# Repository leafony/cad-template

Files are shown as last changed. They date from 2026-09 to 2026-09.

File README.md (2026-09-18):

# Leafony CAD Templates

[Leafony](https://leafony.com/)の拡張リーフ基板を設計するためのCADテンプレート集です。基板外形、Leafony busの接続部、デザインルールなどを設定した設計データを、KiCadとCR-8000 Design Force向けに収録しています。

## 収録テンプレート

| CAD | 使用するバージョン | 内容・使い方 |
| --- | --- | --- |
| KiCad | 10.0系 | 回路図、PCB、プロジェクト設定、専用ライブラリ。[設定・利用手順](KiCad/README.md) |
| CR-8000 Design Force | 2020以降（同梱readmeの記載） | 設計データとライブラリ一覧を含む[ZIPアーカイブ](DesignForce/Leafony_Template/Design_Force_Leafony_Template.zip) |

KiCad版の回路図・PCBはKiCad 10.0形式で保存されています。以前のREADMEにあった「KiCad 6.0.0以降」は、現在のファイルには適用されません。

```text
cad-template/
├── KiCad/
│   ├── README.md
│   ├── Leafony_Template/
│   │   ├── Leafony_Template.kicad_pro   # プロジェクト設定
│   │   ├── Leafony_Template.kicad_sch   # 回路図
│   │   ├── Leafony_Template.kicad_pcb   # 基板レイアウト
│   │   ├── sym-lib-table / fp-lib-table
│   │   ├── lib/                        # 専用シンボル・フットプリント
│   │   └── meta/                       # テンプレート選択画面用の情報
│   └── img/
└── DesignForce/
    └── Leafony_Template/
        └── Design_Force_Leafony_Template.zip
```

## ダウンロード

リポジトリをクローンしてください。

```sh
git clone https://github.com/leafony/cad-template.git
```

Gitを使わない場合は、[GitHubのリポジトリページ](https://github.com/leafony/cad-template)で **Code → Download ZIP** を選び、ダウンロードしたZIPを展開します。ライブラリなどの参照先も必要なため、プロジェクトファイルだけでなくフォルダ全体を取得してください。

## KiCadで使う

1. KiCad 10.0系と標準ライブラリをインストールします。
2. KiCadのユーザーテンプレートの場所に、このリポジトリの `KiCad` フォルダを指定します。
3. 新規プロジェクトのテンプレートとして **Leafony Leaf** を選び、作業用フォルダにプロジェクトを作成します。
4. 作成したプロジェクトでLeafonyのシンボルライブラリを登録し、回路と基板を編集します。

パスの設定例、ライブラリ登録、設計開始時の確認事項は、[KiCad/README.md](KiCad/README.md)を参照してください。

## Design Forceで使う

1. [Design_Force_Leafony_Template.zip](DesignForce/Leafony_Template/Design_Force_Leafony_Template.zip)を作業用フォルダに展開します。
2. `template-design/readme.txt` を確認します。
3. Design Forceで **ファイル → 開く → 設計データ** を選び、`template-design/Design Force/Leafony_Template.dsgn` を開きます。
4. 別名で保存し、設計を開始します。

ZIPには `LeafonyTemplateLibraryList.xlsx` とプレビュー画像も含まれています。対応バージョンと操作手順は、ZIP内のreadmeに基づいています。

## 設計時の確認

テンプレートを基に、使用するリーフとのピン割り当て、電源、I2Cアドレス、部品高さや積層時の干渉を確認してください。基板の寸法・層構成・製造ルールは各CADデータで確認し、製造先の条件に合わせて調整します。設計完了時には回路・基板のルールチェックと製造データの確認を行ってください。

ピン配置、I2Cアドレス、基板製造データの作成については、[Leafony公式ドキュメント「自作リーフ開発」](https://docs.leafony.com/pcb/)を参照してください。

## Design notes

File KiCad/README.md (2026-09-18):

# Leafony KiCad Template

Leafonyの拡張リーフ基板を設計するためのKiCadプロジェクトテンプレートです。Leafony busのシンボルとフットプリント、基板外形、層構成、デザインルールを収録しています。

[リポジトリ全体の案内に戻る](../README.md)

## 対応環境

- **KiCad 10.0系**を使用してください。収録する回路図・PCB・フットプリントはKiCad 10.0で保存されています。
- KiCadの標準シンボル・フットプリントライブラリもインストールしてください。回路図の電源シンボルは標準の `power` ライブラリを参照します。

旧READMEの「KiCad 6.0.0以降」という記載は現在のデータには適用されません。KiCad 9以前は対象外です。KiCadは新しいバージョンで保存したファイルを古いバージョンで開けない場合があります。[KiCad公式マニュアル](https://docs.kicad.org/10.0/ja/kicad/kicad.html)も参照してください。

## ファイル構成

以下のパスは、このREADMEがある `KiCad` フォルダからの相対パスです。

| パス | 用途 |
| --- | --- |
| `Leafony_Template/Leafony_Template.kicad_pro` | プロジェクト設定、デザインルール、ネットクラス |
| `Leafony_Template/Leafony_Template.kicad_sch` | Leafony bus、電源、信号ラベルを配置した回路図 |
| `Leafony_Template/Leafony_Template.kicad_pcb` | 基板外形、接続部、ビア、銅箔ゾーン禁止領域を含むPCB |
| `Leafony_Template/lib/Leafony.kicad_sym` | `Leafony Bus` シンボル |
| `Leafony_Template/lib/Leafony.pretty/` | `CN_F29_B29` フットプリント |
| `Leafony_Template/sym-lib-table` | プロジェクト固有のシンボルライブラリ一覧。配布時点では未登録 |
| `Leafony_Template/fp-lib-table` | プロジェクト固有のフットプリントライブラリ一覧。`Leafony` を登録済み |
| `Leafony_Template/meta/` | テンプレート名・説明・アイコン・プレビュー画像 |

`leafony_template-cache.lib`、`lib/Leafony.dcm`、`lib/Leafony.bak` は旧形式のキャッシュ・説明・バックアップです。新規設定で登録するシンボルライブラリは `lib/Leafony.kicad_sym` です。`.kicad_prl` と `fp-info-cache` は個人設定・キャッシュであり、ライブラリ登録の対象ではありません。

## 1. KiCadとテンプレートを準備する

1. [KiCad公式ダウンロードページ](https://www.kicad.org/download/)から、利用するOS向けのKiCad 10.0系をインストールします。
2. 初回起動時は標準ライブラリを使用する設定を選びます。Linuxなどでライブラリが別パッケージの場合は、標準ライブラリもインストールしてください。
3. [リポジトリの入手手順](../README.md#ダウンロード)に従って、フォルダ全体を取得します。

以降のパスに含まれる `cad-template` は、実際のクローン先またはZIPの展開先に読み替えてください。

## 2. ユーザーテンプレートを登録する

1. KiCadのプロジェクトマネージャーを起動します。
2. **設定 → パスを設定…（Preferences → Configure Paths…）** を開きます。OSや表示言語によりメニュー表記は異なります。
3. `KICAD_USER_TEMPLATE_DIR` を、このリポジトリの **`KiCad` フォルダの絶対パス**に設定します。
4. 設定を保存します。テンプレート一覧に反映されない場合はKiCadを再起動します。

| OS | 設定値の例 |
| --- | --- |
| Windows | `C:/Users/your-name/Documents/cad-template/KiCad` |
| macOS | `/Users/your-name/Documents/cad-template/KiCad` |
| Linux | `/home/your-name/cad-template/KiCad` |

この変数には、`Leafony_Template` を含む親フォルダを指定します。必要な構造は次のとおりです。

```text
<KICAD_USER_TEMPLATE_DIR>/
└── Leafony_Template/
    ├── Leafony_Template.kicad_pro
    ├── Leafony_Template.kicad_sch
    ├── Leafony_Template.kicad_pcb
    ├── lib/
    ├── sym-lib-table
    ├── fp-lib-table
    └── meta/
        └── info.html
```

すでに別のユーザーテンプレートフォルダを利用している場合は、設定値を維持したまま、そのフォルダの下に `Leafony_Template` を丸ごとコピーしても利用できます。

テンプレートの探索場所は[KiCad公式マニュアル](https://docs.kicad.org/10.0/ja/kicad/kicad.html)の「Template locations」に記載されています。

## 3. テンプレートからプロジェクトを作成する

1. プロジェクトマネージャーで **ファイル → 新規プロジェクト…（File → New Project…）** を選びます。
2. テンプレート一覧から **Leafony Leaf** を選びます。必要に応じて一覧をユーザーテンプレートに絞り込みます。
3. **OK** を押し、作業用フォルダと新しいプロジェクト名（例：`my_leaf`）を指定します。
4. 作成された `my_leaf.kicad_pro` を開き、回路図とPCBをプロジェクトマネージャーから起動します。

テンプレートのファイルは新しいプロジェクトへコピーされ、主要なファイル名はプロジェクト名に置き換わります。`lib` フォルダとライブラリ一覧もコピーされます。保存先にはテンプレートの元フォルダとは別の場所を選んでください。

内容を見るだけなら、`Leafony_Template/Leafony_Template.kicad_pro` を直接開けます。自分のリーフを設計するときは、新しく作成したプロジェクトを編集します。

## 4. ライブラリを設定する

作成したプロジェクトで設定します。`${KIPRJMOD}` はKiCadが自動で設定する「現在のプロジェクトフォルダ」です。パス設定画面で追加・変更する必要はありません。

### シンボルライブラリ

配布時の `sym-lib-table` は空です。配置済みのシンボルは回路図内にも保存されていますが、ライブラリからの追加・参照には次の登録が必要です。

1. プロジェクトマネージャーから回路図エディターを開きます。
2. **設定 → シンボルライブラリを管理…（Preferences → Manage Symbol Libraries…）** を開きます。
3. **プロジェクト固有ライブラリ（Project Specific Libraries）** を選びます。
4. 「既存のライブラリを追加」から、作成したプロジェクト内の `lib/Leafony.kicad_sym` を選びます。
5. 登録内容を次の値に合わせ、有効にして保存します。

| 項目 | 値 |
| --- | --- |
| ニックネーム | `Leafony` |
| ライブラリパス | `${KIPRJMOD}/lib/Leafony.kicad_sym` |
| ライブラリ形式 | `KiCad` |

シンボルの選択画面で `Leafony:Leafony Bus` を検索し、表示されることを確認します。既存の `CN1` を使う場合、確認のためにもう1個配置する必要はありません。

### フットプリントライブラリ

`fp-lib-table` に登録済みのため、通常は追加設定不要です。PCBエディターの **設定 → フットプリントライブラリを管理…（Preferences → Manage Footprint Libraries…）** で、プロジェクト固有ライブラリを確認します。

| 項目 | 値 |
| --- | --- |
| ニックネーム | `Leafony` |
| ライブラリパス | `${KIPRJMOD}/lib/Leafony.pretty` |
| ライブラリ形式 | `KiCad` |

`Leafony:CN_F29_B29` が表示されれば設定できています。再登録する場合は、個別の `.kicad_mod` ファイルではなく `Leafony.pretty` フォルダを選びます。

ライブラリを含むプロジェクト全体を移動・共有すれば、上記の相対参照を維持できます。詳細は[KiCad公式「シンボルライブラリの管理」](https://docs.kicad.org/10.0/en/eeschema/eeschema.html#managing-symbol-libraries)を参照してください。

## 5. 設計を開始する

### テンプレートの初期値

以下は収録データの設定値です。製造先に指定する条件と照合してください。

| 項目 | 初期値 |
| --- | --- |
| 基板外形 | `Edge.Cuts` の最大寸法は23 × 20 mm。コネクタ側の幅20 mmに対し、左右に張り出しあり |
| 銅層 | 4層：`F.Cu` / `In1.Cu` / `In2.Cu` / `B.Cu` |
| 基板厚 | 0.8 mm |
| 接続部 | `CN1`、表裏各29接点（`F1`〜`F29`、`B1`〜`B29`） |
| 取り付け穴 | 直径2.05 mmの非めっき穴2個 |
| 最小配線幅・最小クリアランス | 0.1016 mm |
| `Default` ネットクラスの配線幅 | 0.127 mm |
| `Default` ネットクラスのビア径 / ドリル径 | 0.56 mm / 0.30 mm |

基板設定（Board Setup）で層構成、製造上の制約、ネットクラスを確認します。コネクタ領域には銅箔ゾーン禁止領域が設定されています。実際の外形・接点位置・穴位置はPCBデータを基準にしてください。

### 回路・基板を編集する

1. 使用するリーフのピン割り当てを確認し、回路図に部品と配線を追加します。Leafony busの接点番号と既存の信号名を確認しながら接続します。
2. 追加した部品にフットプリントを割り当て、回路図の電気的ルールチェック（ERC）を実行します。
3. **ツール → 回路図からPCBを更新…（Tools → Update PCB from Schematic…）** でPCBへ反映します。
4. 接続部と取り付け穴の位置、他のリーフとの部品干渉を確認し、部品配置・配線を行います。
5. 銅箔ゾーンを再充填し、デザインルールチェック（DRC）で未接続や製造ルール違反を確認します。
6. ガーバーとドリルファイルを出力し、製造先の指定と照合します。

ピン配置や製造データ作成の補足は、[Leafony公式「自作リーフ開発」](https://docs.leafony.com/pcb/)を参照してください。

## よくある問題

| 症状 | 確認すること |
| --- | --- |
| `Leafony Leaf` がテンプレート一覧に出ない | `KICAD_USER_TEMPLATE_DIR` が `Leafony_Template` の親フォルダを指し、その下に `Leafony_Template/meta/info.html` があるか確認します。設定変更後は一覧を開き直すかKiCadを再起動します。 |
| ファイル形式が新しすぎると表示される | KiCad 10.0系で開いているか確認します。 |
| `Leafony` シンボルライブラリが見つからない | 作成したプロジェクトのシンボルライブラリ一覧に `Leafony` を登録します。配布時の一覧には登録されていません。 |
| `Leafony:CN_F29_B29` が見つからない | `lib/Leafony.pretty` と `fp-lib-table` がプロジェクト内にあり、ニックネームとパスが上記設定と一致しているか確認します。 |
| `power` などの標準シンボルが見つからない | KiCadの標準ライブラリがインストールされ、グローバルライブラリ一覧で有効になっているか確認します。 |
| 別のPCへ移したらライブラリを参照できない | `lib` フォルダもコピーし、ライブラリのパスが元のPCの絶対パスではなく `${KIPRJMOD}` を使用しているか確認します。 |

## ライセンス

MIT

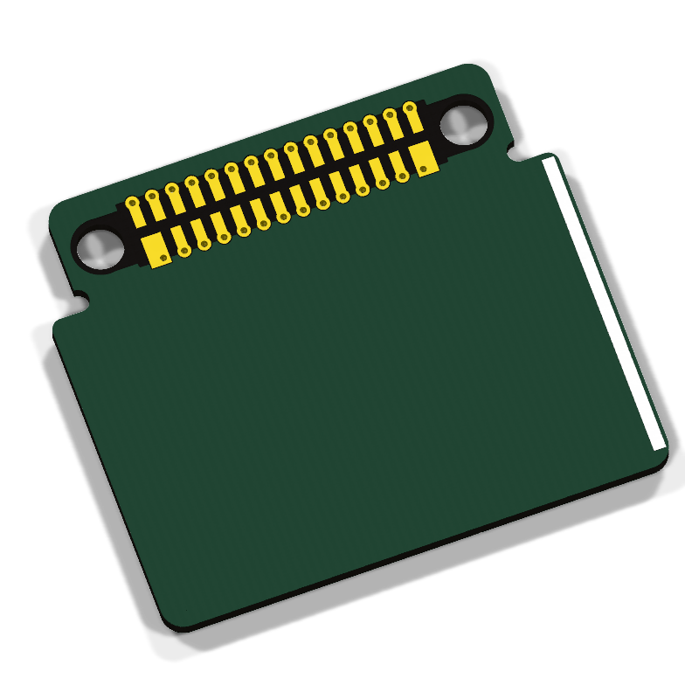
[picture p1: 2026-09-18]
KiCad/Leafony_Template/meta/brd.png
